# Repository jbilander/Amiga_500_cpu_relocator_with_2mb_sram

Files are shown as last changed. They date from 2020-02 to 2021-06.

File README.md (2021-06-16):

# Amiga 500 CPU Relocator with 2MB Fast SRAM
An Amiga 500 cpu relocator with 2MB sram (four 512 x 8 bit), no autoconfig, use addmem to add memory in Z2 space

***
This project is DEPRECATED, superseded by https://github.com/jbilander/SF500
***

This one I did just for fun, wanted to see if I could add 2 MB fast mem to the amiga 500 with just combinatorial logic IC's. It works well but only runs in the standard 7 MHz speed since DTACK is generated by the normal Amiga bus cycle.

The 2MB can be placed in any of the 16-bit Zorro II space slots with addmem, the jumper needs to be set to any of the four base addresses and correspond to your addmem base address. The addmem command can be found on Aminet if you don't have it in C already.

    addmem 200000 400000
    addmem 400000 600000
    addmem 600000 800000
    addmem 800000 A00000

<a href="images/Amiga_500_cpu_relocator_with_2mb_sram_pic1.jpg">
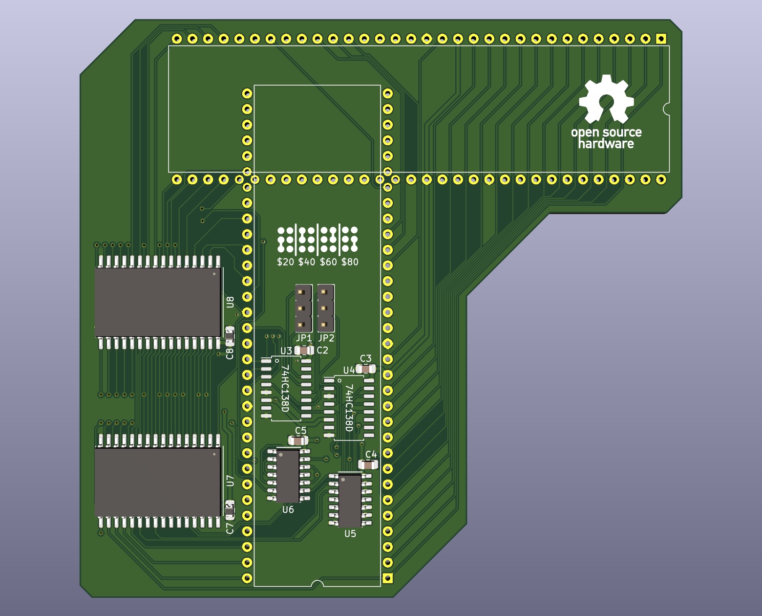
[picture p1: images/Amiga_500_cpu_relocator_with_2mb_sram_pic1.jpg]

</a>
<a href="images/Amiga_500_cpu_relocator_with_2mb_sram_pic2.jpg">
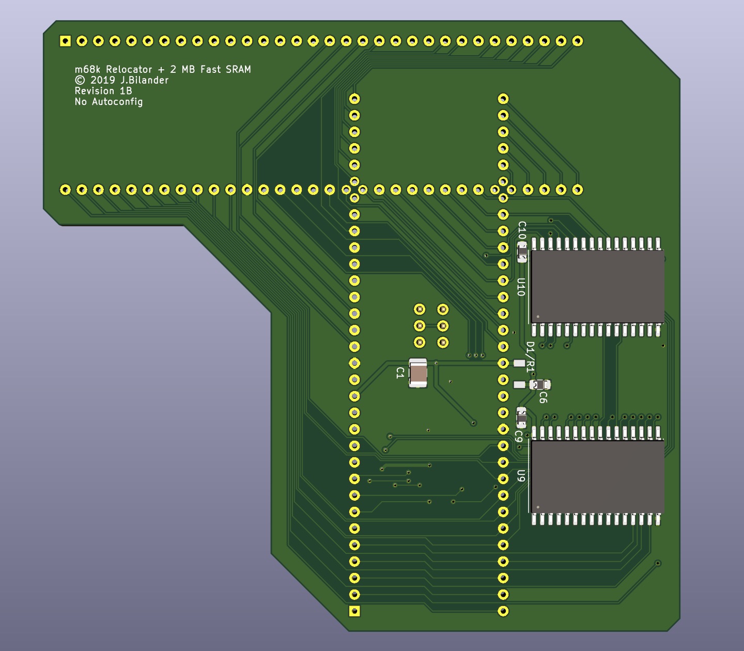
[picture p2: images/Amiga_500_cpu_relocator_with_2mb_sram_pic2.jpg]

</a>
<a href="images/Amiga_500_cpu_relocator_with_2mb_sram_pic3.jpg">
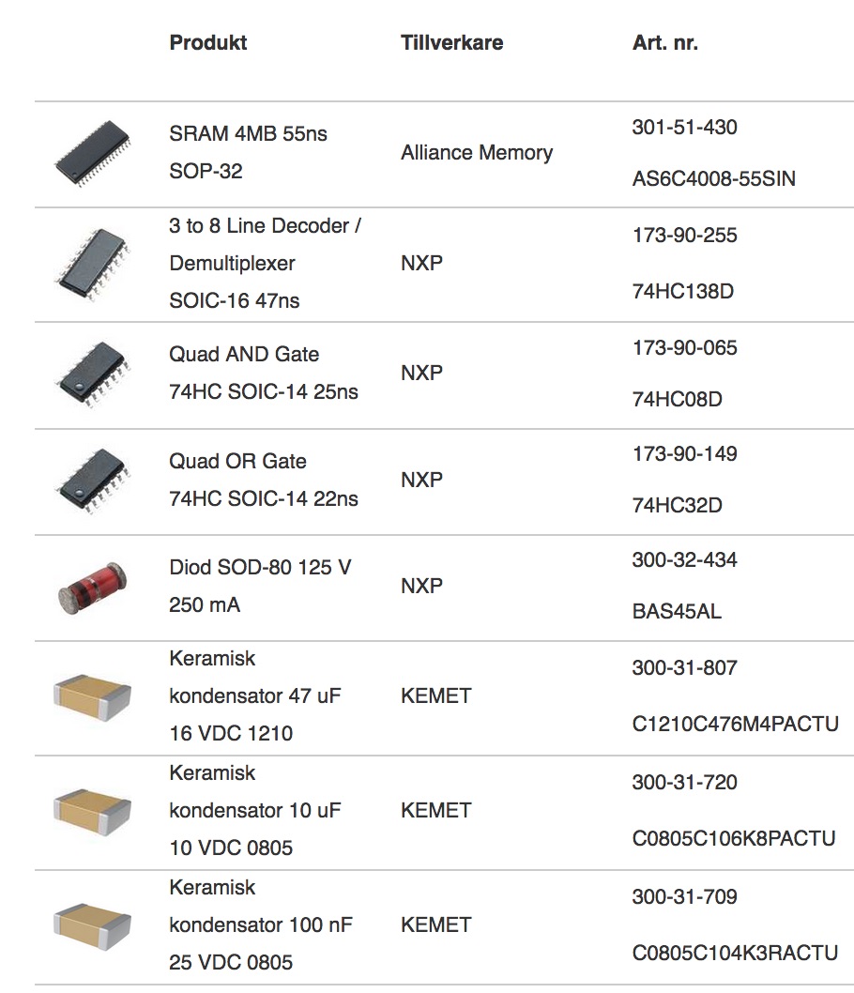
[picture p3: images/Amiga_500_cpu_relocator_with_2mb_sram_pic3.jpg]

</a>

***

<a href="images/Amiga_500_cpu_relocator_with_2mb_sram_pic4.jpg">
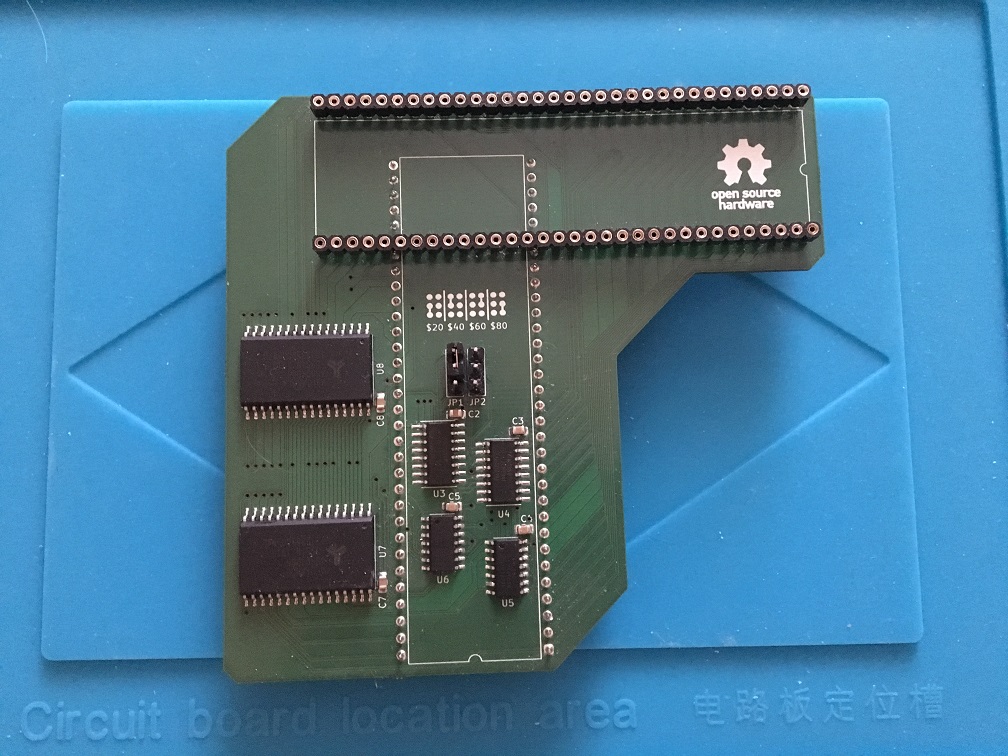
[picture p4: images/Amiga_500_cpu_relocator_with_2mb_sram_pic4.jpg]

</a>
<a href="images/Amiga_500_cpu_relocator_with_2mb_sram_pic5.jpg">
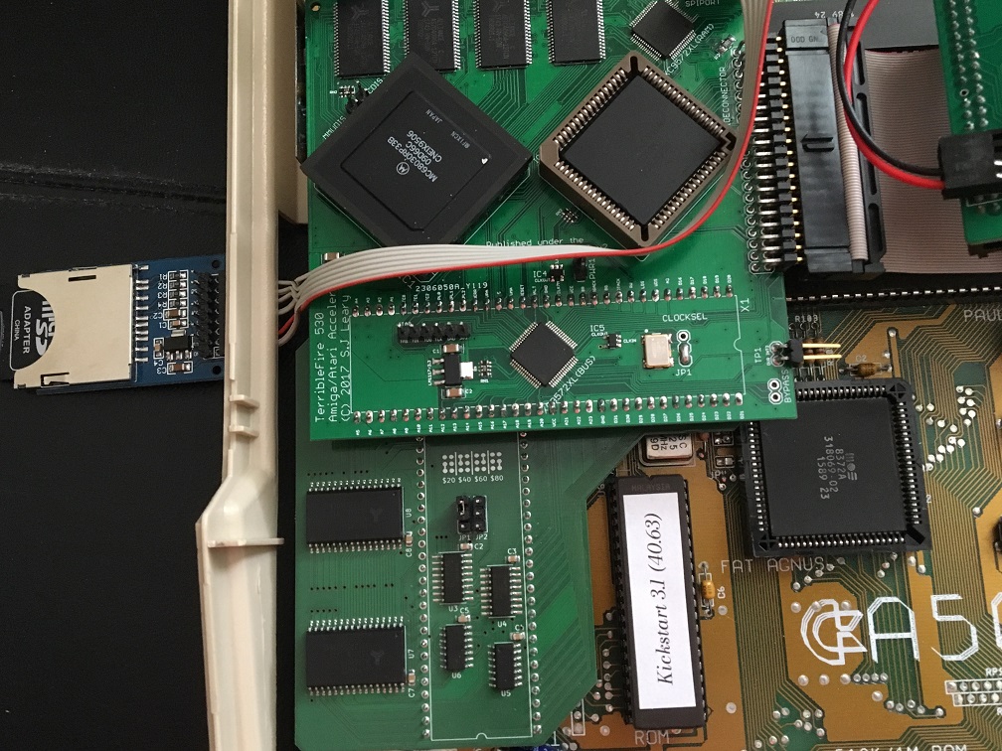
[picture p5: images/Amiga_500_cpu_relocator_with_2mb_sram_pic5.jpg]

</a>
<a href="images/Amiga_500_cpu_relocator_with_2mb_sram_pic6.jpg">
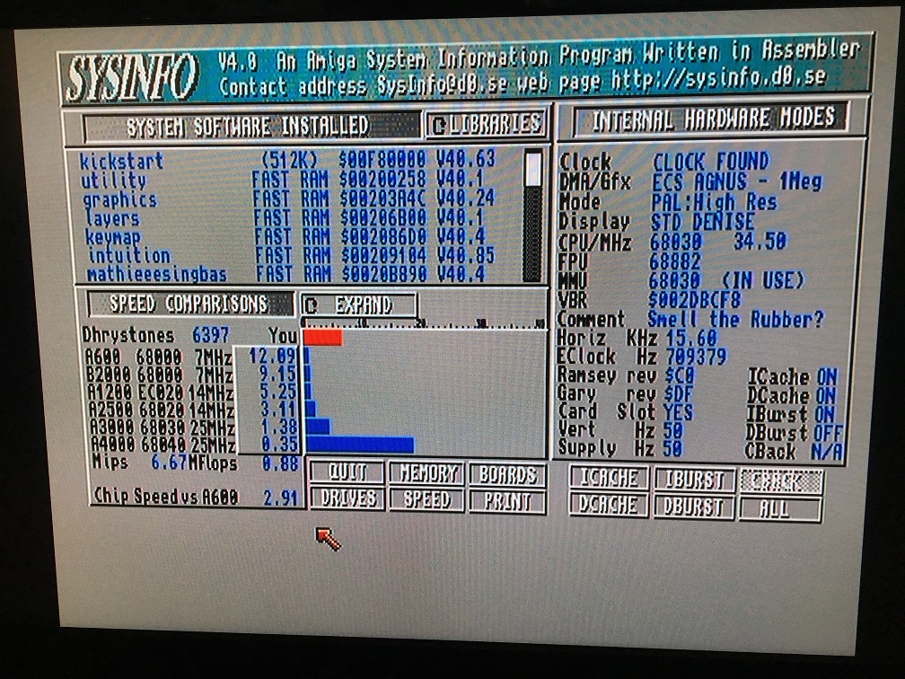
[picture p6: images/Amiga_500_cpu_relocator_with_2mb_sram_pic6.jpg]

</a>
<br /><br />
Testing the relocator with a TF530 that has 2 MB onboard ram. Setting the relocator ram as higher priority memory really slows down the accelelerator since it has to insert wait states to talk to the 7 MHz bus.
<br /><br />
<a href="images/Amiga_500_cpu_relocator_with_2mb_sram_pic7.jpg">
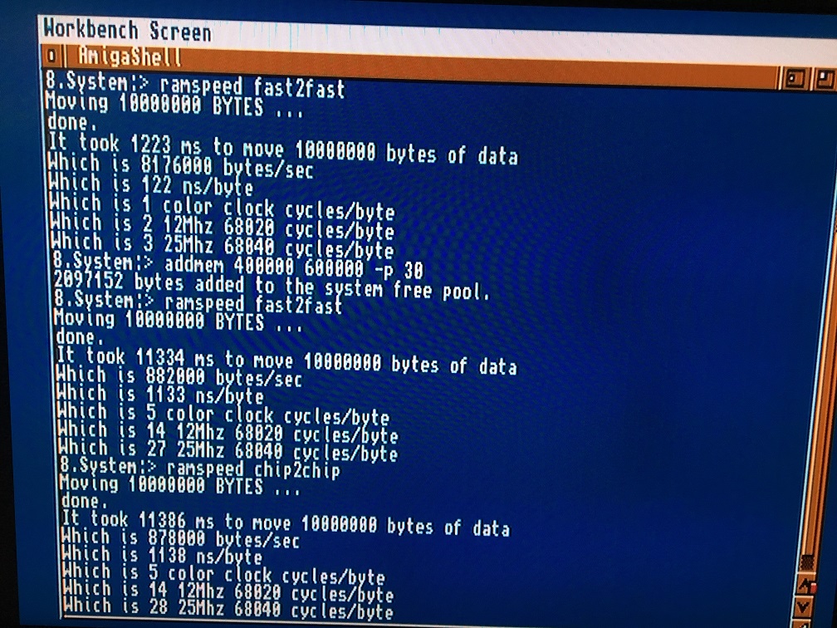
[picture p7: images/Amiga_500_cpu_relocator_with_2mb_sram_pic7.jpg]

</a>
<a href="images/Amiga_500_cpu_relocator_with_2mb_sram_pic8.jpg">
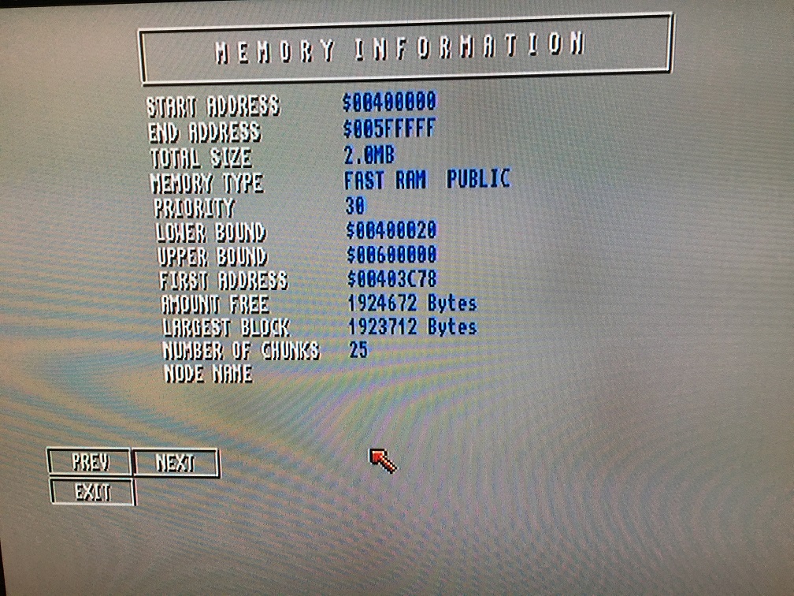
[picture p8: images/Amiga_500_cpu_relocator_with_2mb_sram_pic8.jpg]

</a>
<a href="images/Amiga_500_cpu_relocator_with_2mb_sram_pic9.jpg">
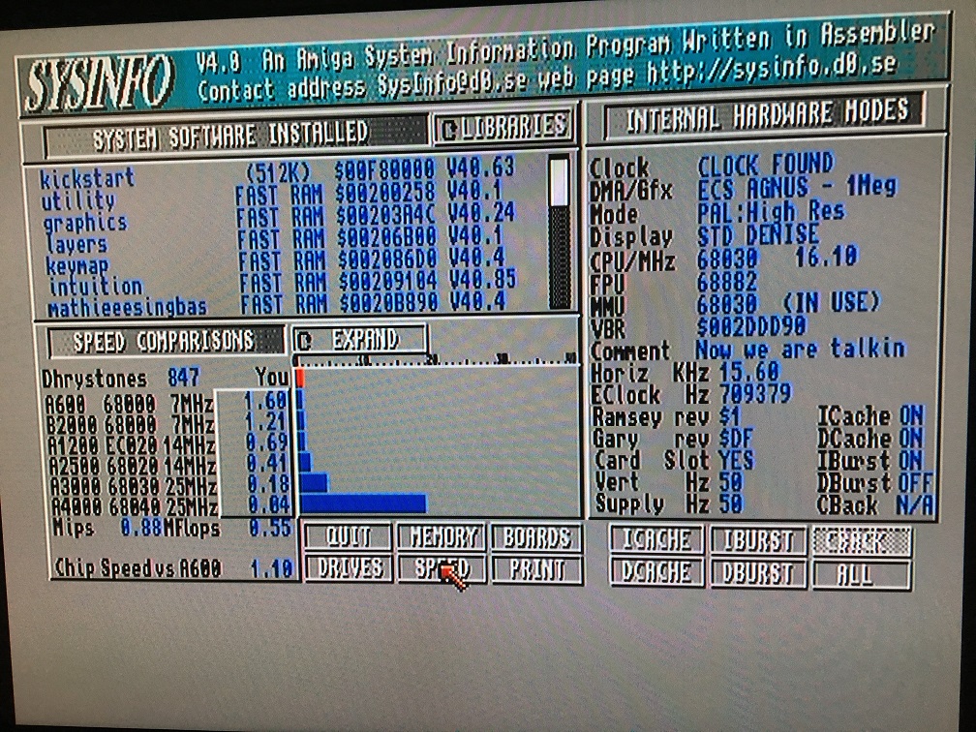
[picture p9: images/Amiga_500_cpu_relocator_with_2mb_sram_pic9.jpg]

</a>

***

Here testing with a TF534 and adding ram at base $600000, works ok but really no need, this was just for fun....

<a href="images/Amiga_500_cpu_relocator_with_2mb_sram_pic10.jpg">
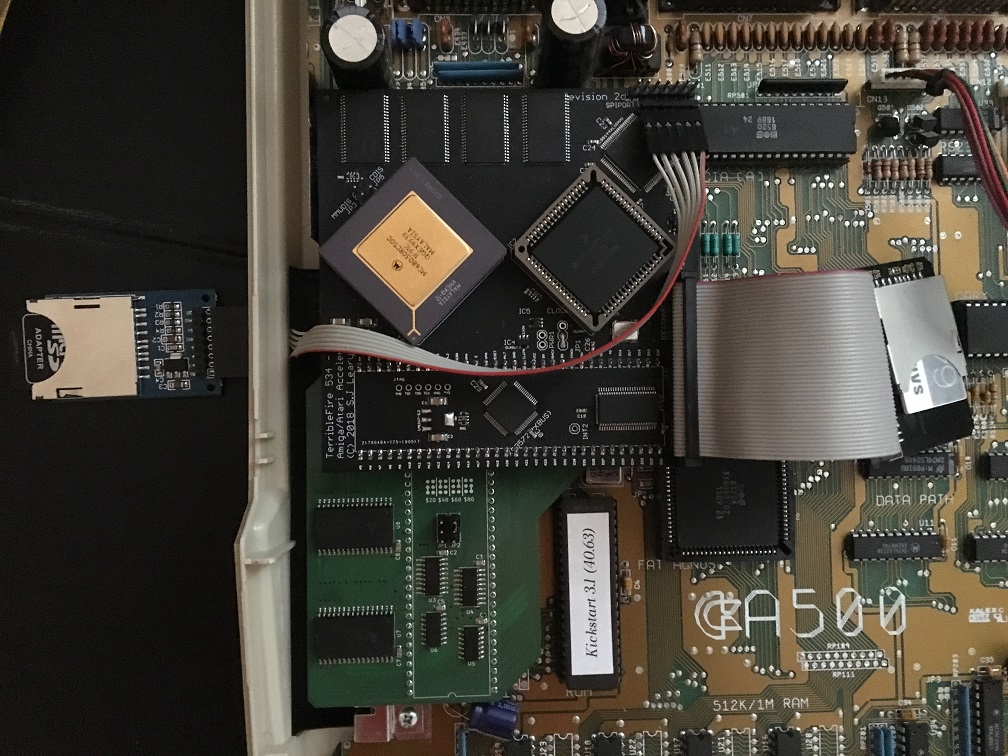
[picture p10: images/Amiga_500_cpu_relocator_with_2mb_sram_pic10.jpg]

</a>
<a href="images/Amiga_500_cpu_relocator_with_2mb_sram_pic11.jpg">
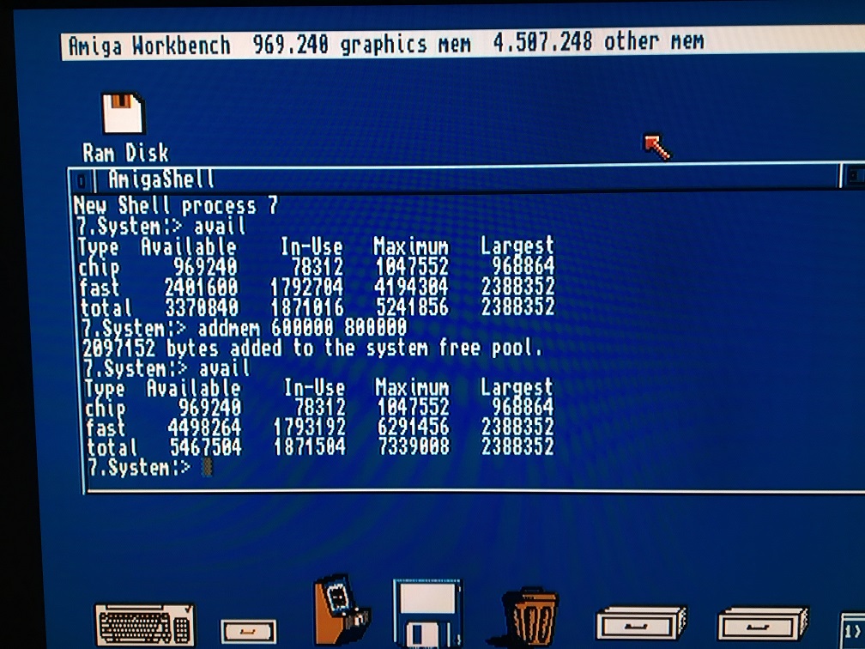
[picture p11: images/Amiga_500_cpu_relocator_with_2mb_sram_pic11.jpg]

</a>
<a href="images/Amiga_500_cpu_relocator_with_2mb_sram_pic12.jpg">
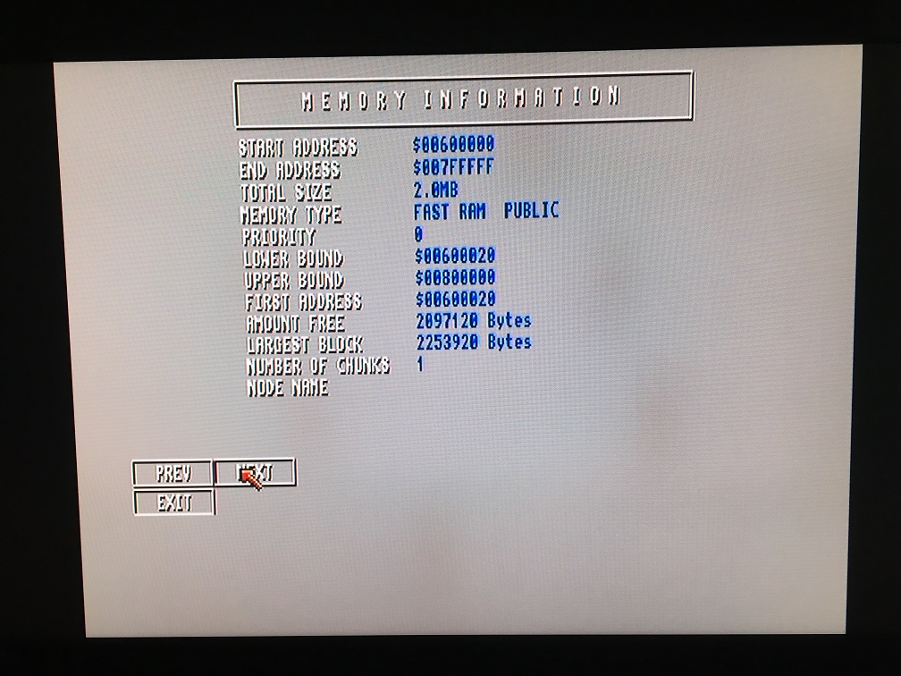
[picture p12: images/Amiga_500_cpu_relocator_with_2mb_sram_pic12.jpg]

</a>

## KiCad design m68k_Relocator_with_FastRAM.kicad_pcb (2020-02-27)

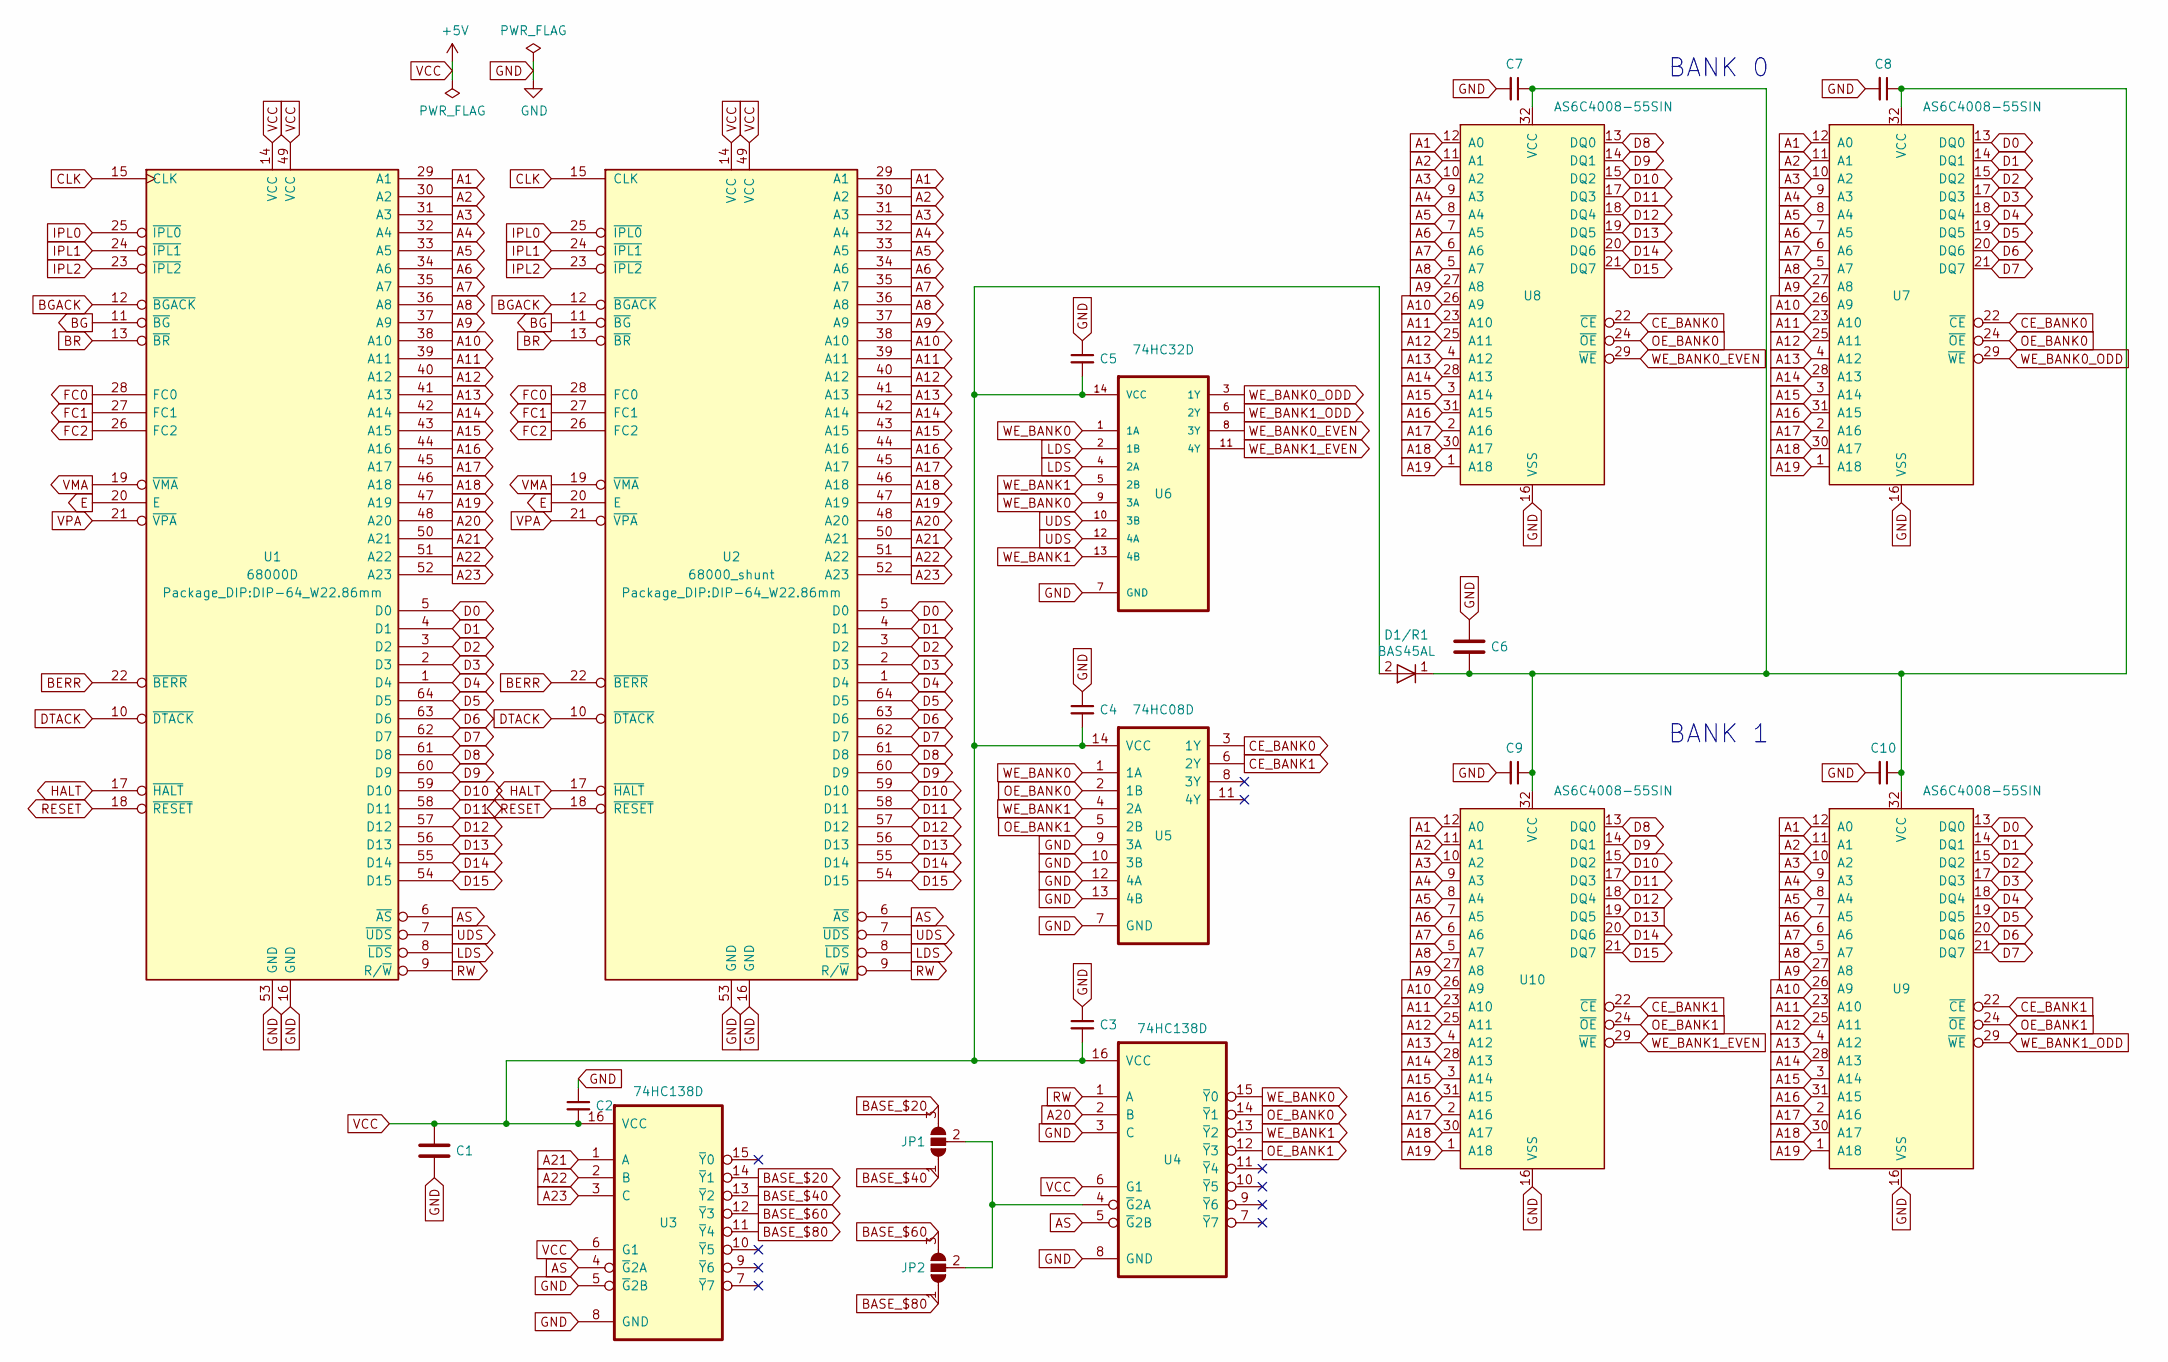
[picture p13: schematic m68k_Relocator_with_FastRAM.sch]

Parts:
C1: C; C_1210_3225Metric_Pad1.42x2.65mm_HandSolder
C2, C3, C4, C5: C_Small; C_0805_2012Metric_Pad1.15x1.40mm_HandSolder
C6: C; D_0805_2012Metric_Pad1.15x1.40mm_HandSolder
C7, C8, C9, C10: C_Small; D_0805_2012Metric_Pad1.15x1.40mm_HandSolder
D1/R1: BAS45AL; SOD80C
JP1, JP2: SolderJumper_3_Open; PinHeader_1x03_P2.54mm_Vertical
U1: 68000D; DIP-64_W22.86mm
U2: 68000_shunt; DIP-64_W22.86mm
U3, U4: 74HC138D; SOIC-16_4.55x10.3mm_P1.27mm
U5: 74HC08D; SOIC-14_3.9x8.7mm_P1.27mm
U6: 74HC32D; SOIC-14_3.9x8.7mm_P1.27mm
U7, U8, U9, U10: AS6C4008-55SIN; SSOP-32_11.305x20.495mm_P1.27mm

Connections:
A1: U1.29 (A1), U2.29 (A1), U7.12 (A0), U8.12 (A0), U9.12 (A0), U10.12 (A0)
A2: U1.30 (A2), U2.30 (A2), U7.11 (A1), U8.11 (A1), U9.11 (A1), U10.11 (A1)
A3: U1.31 (A3), U2.31 (A3), U7.10 (A2), U8.10 (A2), U9.10 (A2), U10.10 (A2)
A4: U1.32 (A4), U2.32 (A4), U7.9 (A3), U8.9 (A3), U9.9 (A3), U10.9 (A3)
A5: U1.33 (A5), U2.33 (A5), U7.8 (A4), U8.8 (A4), U9.8 (A4), U10.8 (A4)
A6: U1.34 (A6), U2.34 (A6), U7.7 (A5), U8.7 (A5), U9.7 (A5), U10.7 (A5)
A7: U1.35 (A7), U2.35 (A7), U7.6 (A6), U8.6 (A6), U9.6 (A6), U10.6 (A6)
A8: U1.36 (A8), U2.36 (A8), U7.5 (A7), U8.5 (A7), U9.5 (A7), U10.5 (A7)
A9: U1.37 (A9), U2.37 (A9), U7.27 (A8), U8.27 (A8), U9.27 (A8), U10.27 (A8)
A10: U1.38 (A10), U2.38 (A10), U7.26 (A9), U8.26 (A9), U9.26 (A9), U10.26 (A9)
A11: U1.39 (A11), U2.39 (A11), U7.23 (A10), U8.23 (A10), U9.23 (A10), U10.23 (A10)
A12: U1.40 (A12), U2.40 (A12), U7.25 (A11), U8.25 (A11), U9.25 (A11), U10.25 (A11)
A13: U1.41 (A13), U2.41 (A13), U7.4 (A12), U8.4 (A12), U9.4 (A12), U10.4 (A12)
A14: U1.42 (A14), U2.42 (A14), U7.28 (A13), U8.28 (A13), U9.28 (A13), U10.28 (A13)
A15: U1.43 (A15), U2.43 (A15), U7.3 (A14), U8.3 (A14), U9.3 (A14), U10.3 (A14)
A16: U1.44 (A16), U2.44 (A16), U7.31 (A15), U8.31 (A15), U9.31 (A15), U10.31 (A15)
A17: U1.45 (A17), U2.45 (A17), U7.2 (A16), U8.2 (A16), U9.2 (A16), U10.2 (A16)
A18: U1.46 (A18), U2.46 (A18), U7.30 (A17), U8.30 (A17), U9.30 (A17), U10.30 (A17)
A19: U1.47 (A19), U2.47 (A19), U7.1 (A18), U8.1 (A18), U9.1 (A18), U10.1 (A18)
A20: U1.48 (A20), U2.48 (A20), U4.2 (B)
A21: U1.50 (A21), U2.50 (A21), U3.1 (A)
A22: U1.51 (A22), U2.51 (A22), U3.2 (B)
A23: U1.52 (A23), U2.52 (A23), U3.3 (C)
AS: U1.6 (~AS), U2.6 (~AS), U3.4 (~G~2A), U4.5 (~G~2B)
BASE_$20: JP1.3 (B), U3.14 (~Y~1)
BASE_$40: JP1.1 (A), U3.13 (~Y~2)
BASE_$60: JP2.3 (B), U3.12 (~Y~3)
BASE_$80: JP2.1 (A), U3.11 (~Y~4)
BERR: U1.22 (~BERR), U2.22 (~BERR)
BG: U1.11 (~BG), U2.11 (~BG)
BGACK: U1.12 (~BGACK), U2.12 (~BGACK)
BR: U1.13 (~BR), U2.13 (~BR)
CE_BANK0: U5.3 (1Y), U7.22 (~CE), U8.22 (~CE)
CE_BANK1: U5.6 (2Y), U9.22 (~CE), U10.22 (~CE)
CLK: U1.15 (CLK), U2.15 (CLK)
D0: U1.5 (D0), U2.5 (D0), U7.13 (DQ0), U9.13 (DQ0)
D1: U1.4 (D1), U2.4 (D1), U7.14 (DQ1), U9.14 (DQ1)
D2: U1.3 (D2), U2.3 (D2), U7.15 (DQ2), U9.15 (DQ2)
D3: U1.2 (D3), U2.2 (D3), U7.17 (DQ3), U9.17 (DQ3)
D4: U1.1 (D4), U2.1 (D4), U7.18 (DQ4), U9.18 (DQ4)
D5: U1.64 (D5), U2.64 (D5), U7.19 (DQ5), U9.19 (DQ5)
D6: U1.63 (D6), U2.63 (D6), U7.20 (DQ6), U9.20 (DQ6)
D7: U1.62 (D7), U2.62 (D7), U7.21 (DQ7), U9.21 (DQ7)
D8: U1.61 (D8), U2.61 (D8), U8.13 (DQ0), U10.13 (DQ0)
D9: U1.60 (D9), U2.60 (D9), U8.14 (DQ1), U10.14 (DQ1)
D10: U1.59 (D10), U2.59 (D10), U8.15 (DQ2), U10.15 (DQ2)
D11: U1.58 (D11), U2.58 (D11), U8.17 (DQ3), U10.17 (DQ3)
D12: U1.57 (D12), U2.57 (D12), U8.18 (DQ4), U10.18 (DQ4)
D13: U1.56 (D13), U2.56 (D13), U8.19 (DQ5), U10.19 (DQ5)
D14: U1.55 (D14), U2.55 (D14), U8.20 (DQ6), U10.20 (DQ6)
D15: U1.54 (D15), U2.54 (D15), U8.21 (DQ7), U10.21 (DQ7)
DTACK: U1.10 (~DTACK), U2.10 (~DTACK)
E: U1.20 (E), U2.20 (E)
FC0: U1.28 (FC0), U2.28 (FC0)
FC1: U1.27 (FC1), U2.27 (FC1)
FC2: U1.26 (FC2), U2.26 (FC2)
GND: C1.2, C2.1, C3.1, C4.1, C5.1, C6.1, C7.2, C8.2, C9.2, C10.2, U1.16 (GND), U1.53 (GND), U2.16 (GND), U2.53 (GND), U3.5 (~G~2B), U3.8 (GND), U4.3 (C), U4.8 (GND), U5.7 (GND), U5.9 (3A), U5.10 (3B), U5.12 (4A), U5.13 (4B), U6.7 (GND), U7.16 (VSS), U8.16 (VSS), U9.16 (VSS), U10.16 (VSS)
HALT: U1.17 (~HALT), U2.17 (~HALT)
IPL0: U1.25 (~IPL0), U2.25 (~IPL0)
IPL1: U1.24 (~IPL1), U2.24 (~IPL1)
IPL2: U1.23 (~IPL2), U2.23 (~IPL2)
LDS: U1.8 (~LDS), U2.8 (~LDS), U6.2 (1B), U6.4 (2A)
unnamed: C6.2, C7.1, C8.1, C9.1, C10.1, D1/R1.1, U7.32 (VCC), U8.32 (VCC), U9.32 (VCC), U10.32 (VCC)
unnamed: JP1.2 (C), JP2.2 (C), U4.4 (~G~2A)
OE_BANK0: U4.14 (~Y~1), U5.2 (1B), U7.24 (~OE), U8.24 (~OE)
OE_BANK1: U4.12 (~Y~3), U5.5 (2B), U9.24 (~OE), U10.24 (~OE)
RESET: U1.18 (~RESET), U2.18 (~RESET)
RW: U1.9 (R/~W), U2.9 (R/~W), U4.1 (A)
UDS: U1.7 (~UDS), U2.7 (~UDS), U6.10 (3B), U6.12 (4A)
VCC: C1.1, C2.2, C3.2, C4.2, C5.2, D1/R1.2, U1.14 (VCC), U1.49 (VCC), U2.14 (VCC), U2.49 (VCC), U3.6 (G1), U3.16 (VCC), U4.6 (G1), U4.16 (VCC), U5.14 (VCC), U6.14 (VCC)
VMA: U1.19 (~VMA), U2.19 (~VMA)
VPA: U1.21 (~VPA), U2.21 (~VPA)
WE_BANK0: U4.15 (~Y~0), U5.1 (1A), U6.1 (1A), U6.9 (3A)
WE_BANK0_EVEN: U6.8 (3Y), U8.29 (~WE)
WE_BANK0_ODD: U6.3 (1Y), U7.29 (~WE)
WE_BANK1: U4.13 (~Y~2), U5.4 (2A), U6.5 (2B), U6.13 (4B)
WE_BANK1_EVEN: U6.11 (4Y), U10.29 (~WE)
WE_BANK1_ODD: U6.6 (2Y), U9.29 (~WE)

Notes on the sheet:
BANK 1
BANK 0

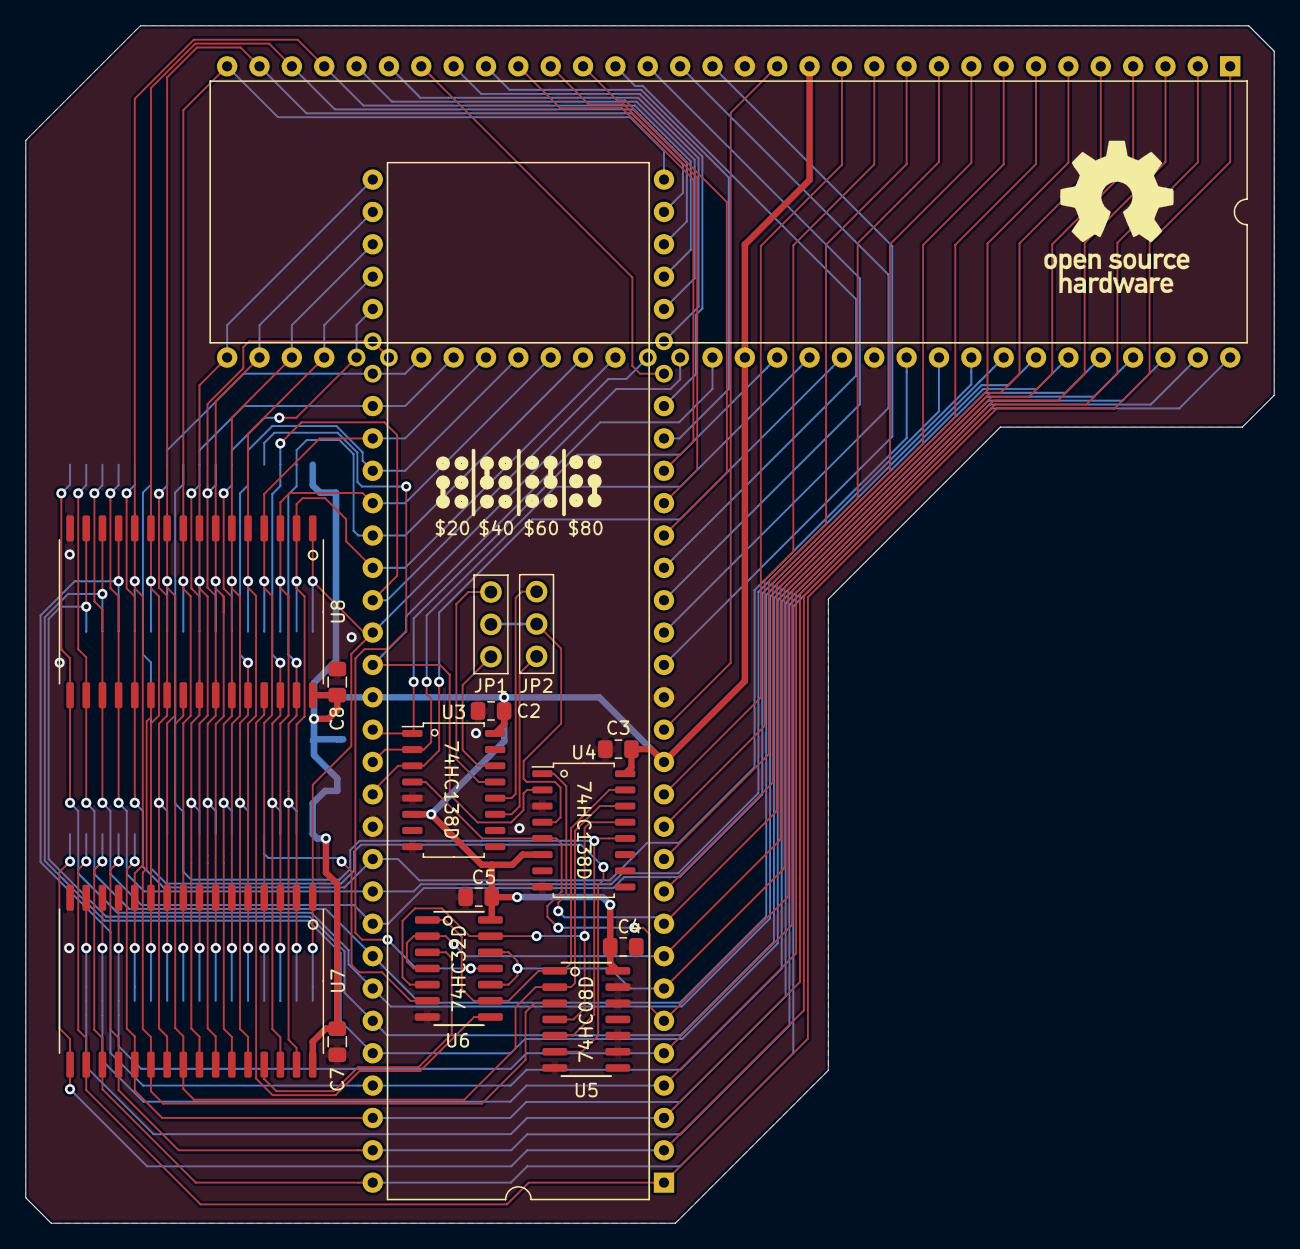
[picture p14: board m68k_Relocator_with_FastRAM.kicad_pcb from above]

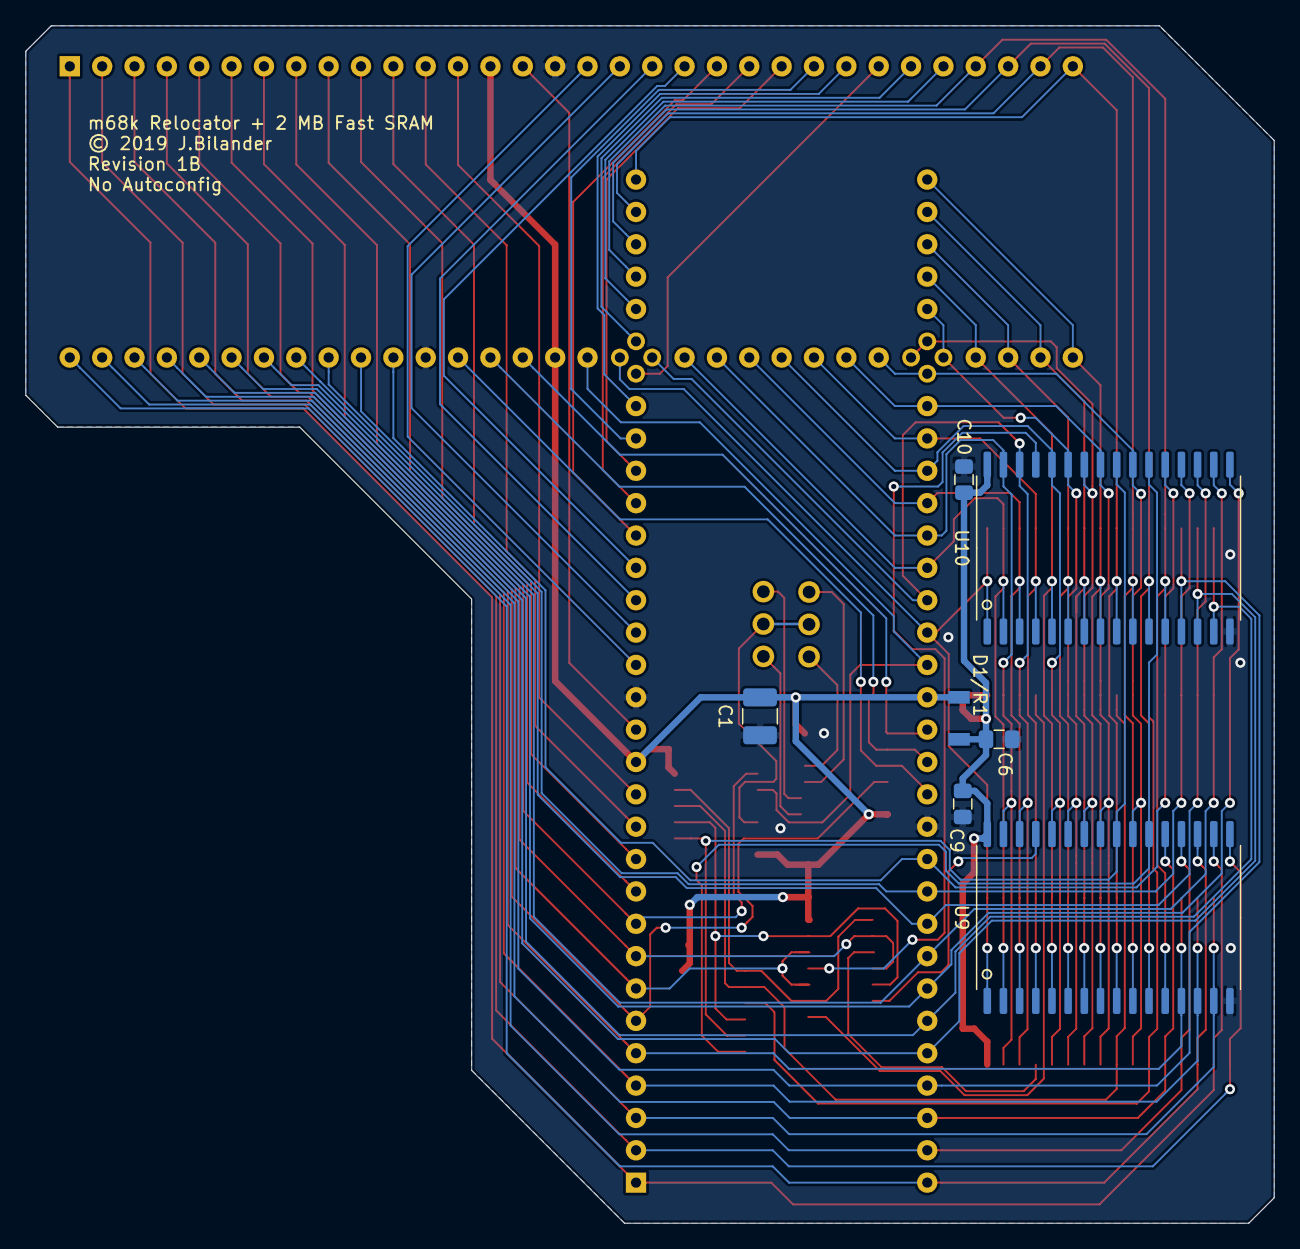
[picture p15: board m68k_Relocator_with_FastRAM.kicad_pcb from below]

Board: 2 copper layers, 98.0 x 94.0 mm, 23 parts (7 on the bottom side), 78 nets.

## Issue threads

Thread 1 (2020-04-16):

[Question]Replace BAS45AL by something else ?

Twisty59, 2020-04-16:
Hello,

I'm building this awesome board right now but unfortunately I can't get the BAS45AL diode to my local electronic supply store.
Is it possible to replace with something else ?

Thanks

jbilander, 2020-04-17:
Hello, Yes you can replace with a similar spec Low-leakage current switching diode (SOD-80 package). In fact I think it's not needed and you could just solder blob across pads or solder in a Zero Ohm resistor. I haven't tried it myself though. To play it safe replace with a similar diode. Best of luck. -jb

Twisty59, 2020-04-17:
Hello
I will try to find a similar diode to replace.
Thanks you so much for your reply and sharing with us your project !

Closed 2020-04-17.

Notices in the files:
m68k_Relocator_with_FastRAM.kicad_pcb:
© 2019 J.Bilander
